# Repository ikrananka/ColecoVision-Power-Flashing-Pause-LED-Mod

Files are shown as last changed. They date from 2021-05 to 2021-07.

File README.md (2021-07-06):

# ColecoVision Power/Flashing Pause LED Mod

## Introduction

This mod for the ColecoVision games console has two functions.  The first is to provide a continuously lit red power LED.  This LED will illuminate whenever the ColecoVision is turned on and not paused.  The second function is to provide a hardwired, physical switch, to pause operation of the ColecoVision allowing you to pause a game at any point and resume play at your leisure.  A unique feature of this mod is that when paused the power/pause LED flashes to indicate that the system is paused.  The rate of flashing is user adjustable from 0.6 to 3.3Hz.  When pause is turned off the flashing LED reverts to being continuously lit (until the system is either paused again or is turned off).
The pause function is achieved by pulling the WAIT line of the ColecoVision’s Z80 CPU low.  This in effect pauses all Z80 processing and therefore pauses the game you’re playing.  However, the audio is not paused and will continue to emit the last note/tone which can be very annoying.  Therefore, this mod not only pauses the Z80 processor but also disconnects the audio output whenever pause is engaged.

The Finished Product


## FAQ

Q.	Will this work with Super Game Module (SGM1) games?

A.	Yes (if you wire the audio as recommended later in this document).  All SGM enhanced games still use the Z80 processor and so they will pause when the Z80 is paused just like any other ColecoVision game.  However, SGM enhanced audio is fed to the ColecoVision via the expansion port (EXAUD), bypassing the ColecoVision’s onboard sound from the SN76489A.  Therefore, it is important that when paused, audio is disconnected from a location after the point where audio from the SN76489A and EXAUD combine.  This is easy to do and instructions for this are provided later in this document.

Q.	Will this work with the upcoming Super Game Module 2 (SGM2)?

A.	Yes and No.  According to the latest information from Opcode Games, the SGM2 will be backwards compatible with SGM1 games and the pause mod will function in the same way as described in the answer above.  However, SGM2 specific games will use the new Z80 and/or 16-bit CPUs that are contained in the SGM2 unit and these cannot be paused using this mod.  However, Opcode Games has stated that “pause will be implemented in software for these games because of the dual CPU design” and so a hardware pause solution is not needed.  You never know, perhaps Opcode Games will make the SGM2s power LED flash when a game is paused!!!

Q.	Does this work with the Expansion Module #1?

A.	No.  The expansion module #1 uses its own processor and audio chip and like the SGM2 cannot be paused by this mod.  Be aware that moving the pause switch to the pause position while playing an expansion module #1 game may disconnect the audio so leave the switch in the normal position when playing these games.

Q.	Is the mod reversable?

A.	The mod is mostly reversable other than the fact that you must drill two large holes in the ColecoVision’s top housing.  These holes are obviously not reversable.

Q. Can the top and bottom halves of the ColecoVision console shell be separated during system maintenance/troubleshooting?

A. Yes.  A pair of 6-pin Molex connectors ae included in the design that when disconnected from each other allow the top and bottom halves of the ColecoVision console shell to be completely separated from each other.

Q.	Can the switch and circuit board be removed for maintenance/troubleshooting?

A.	Yes.  Assuming you don’t use any glue during the installation, which isn’t necessary, then the switch and circuit board can be easily removed.

## The Kit
 
The installation kit contains the following items:
1.	ColecoVision Power/Pause LED Mod PCB.
2.	Motherboard wiring harness.
3.	Pause switch wiring harness (includes pause switch).
4.	Circuit board custom spacer.
5.	Pause switch nut (used to hold switch and circuit board in place).
6.	LED holder.

## Bill of Materials

Please download and refer to the [Bill of Materials](https://github.com/ikrananka/ColecoVision-Power-Flashing-Pause-LED-Mod/blob/main/Bill%20of%20Materials%20v1.0.pdf) contained in this repository.

## Printed Circuit Board

Included in this repository are the PCB schematic and board files created using Eagle v9.1.0.  I have also included Gerber files that are suitable for ordering PCBs from [JLCPCB](https://jlcpcb.com).  If you plan on ordering boards from other PCB manufacturers then you may need to create new gerber files that adhere to that manufacturer's requirements.

### LED Installation

Note that the LED should be soldered onto the underside of the PCB, i.e. the opposite side to all of the other components.  Critically, the LED **MUST** be slightly raised by 0.75mm (30 thou) above the PCB surface as shown below.  I use small pieces of plastic card (0.75mm thick) to do this, held in place with sticky tack, and then solder the LED in place.  Don't forget to remove the pieces of plastic after soldering the LED.

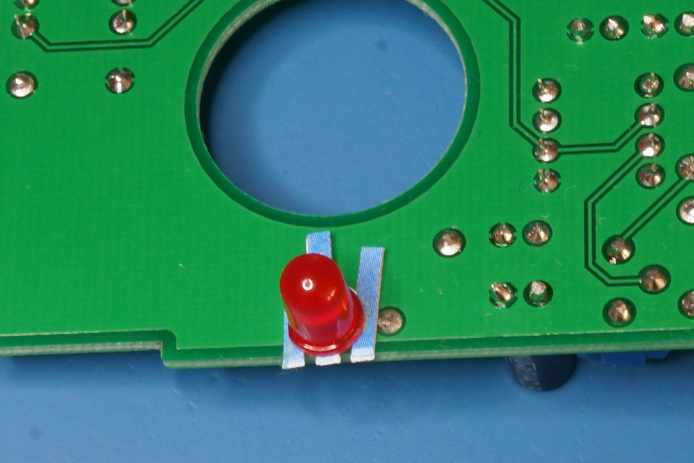
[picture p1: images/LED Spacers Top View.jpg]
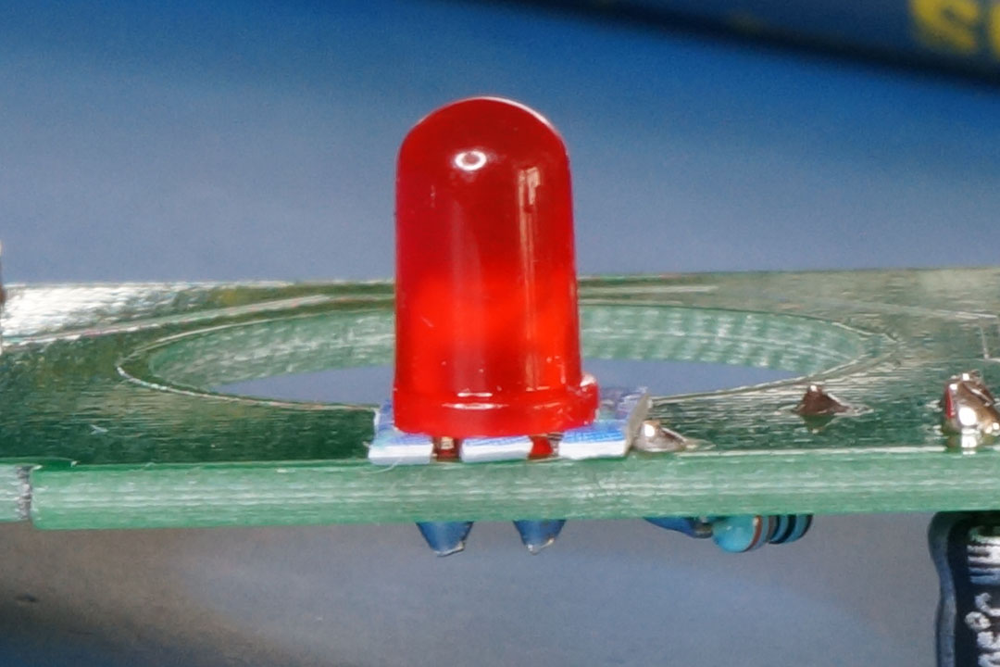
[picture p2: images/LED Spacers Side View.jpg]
 

## Construction of the Wiring Harnesses
### Tools Needed

- Soldering iron and solder
- Wire cutter
- Wire stripper
- Crimping tool (I use a [Waldom W-HT-1921 crimping tool](https://www.digikey.com/en/products/detail/gc-electronics/W-HT-1921/26396)).

### Wire

Note that my preference is to use multistrand (7/32) 24AWG wire for this kit.  Nevertheless, 22AWG multistrand wire would also likely work fine.

### Wire Lengths and Connections

Refer to the following wiring diagram and photographs for details.  Use the appropriate crimps (from the Bill of Materials) for wires that are part of the Molex connectors.  I recommend soldering the wires to the four connections on the back of the rocker switch.

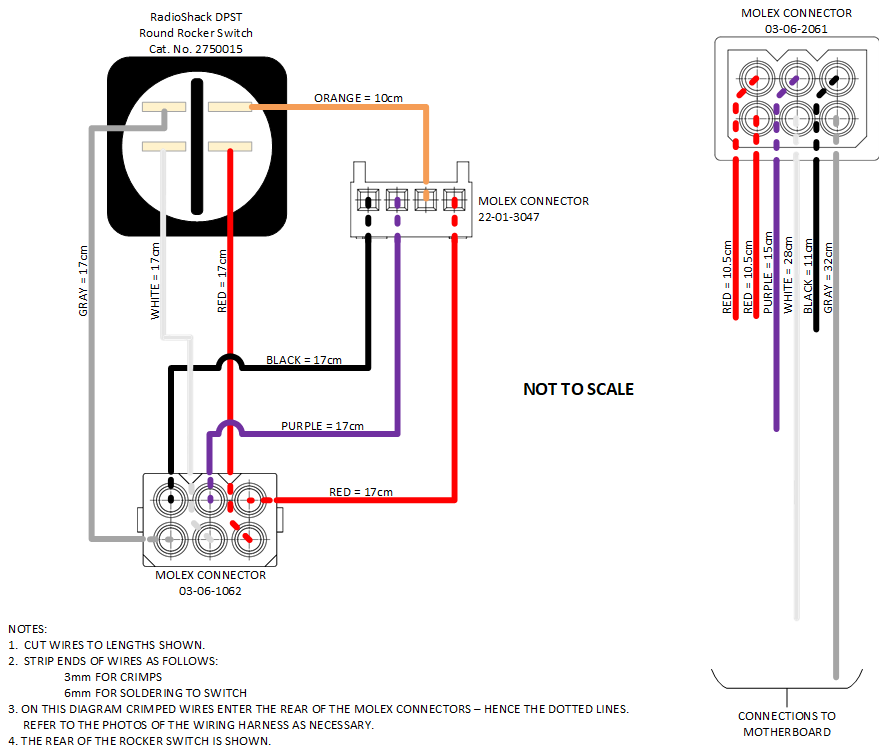
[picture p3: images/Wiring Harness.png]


## The Custom Spacer

The custom spacer provides support under the PCB when tightening the nut that holds the rocker switch and PCB in place.  It is simply a 3D printed circular spacer/washer with the following dimensions:

- ID = 20.5mm
- OD = 26.5mm
- Thickness = 3mm

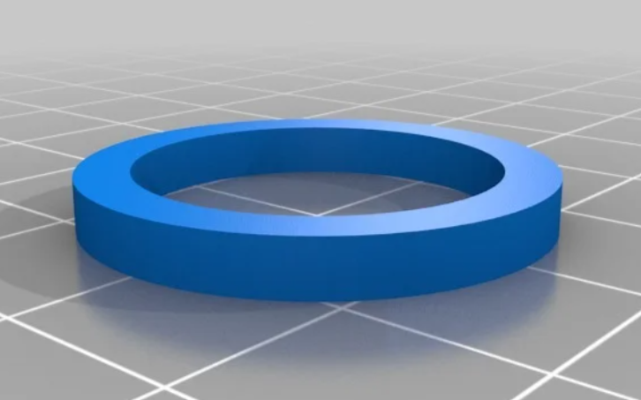
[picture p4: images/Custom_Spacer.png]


You can either download the design from [thingiverse.com](https://www.thingiverse.com/thing:3446247) or from the ["Custom_Spacer.zip"](Custom_Spacer.zip) file included in this repository.

## The Pause Switch Nut

The pause switch nut is included with the purchase of the Radio Shack DPDT switch from the bill of materials.  However, the nut needs to be modified slightly by lightly sanding down the ridges that will press against the PCB when installed.  To do this I typically use 300 grit sandpaper face up on a flat surface and hold the nut with the ridges flat against the sandpaper.  I then slide the nut over the sandpaper in a circular motion while pressing down.  The photo below shows the nut before and after and should give you a good idea of how much of the ridges you need to sand down.  Note that if you don't sand down these ridges then you will find that you won't be able to screw the nut onto the switch when it is installed in the ColecoVision with the spacer and PCB installed.  Sanding down the ridges allows the nut to get close enough to the thread on the switch so that it can be tightened up.

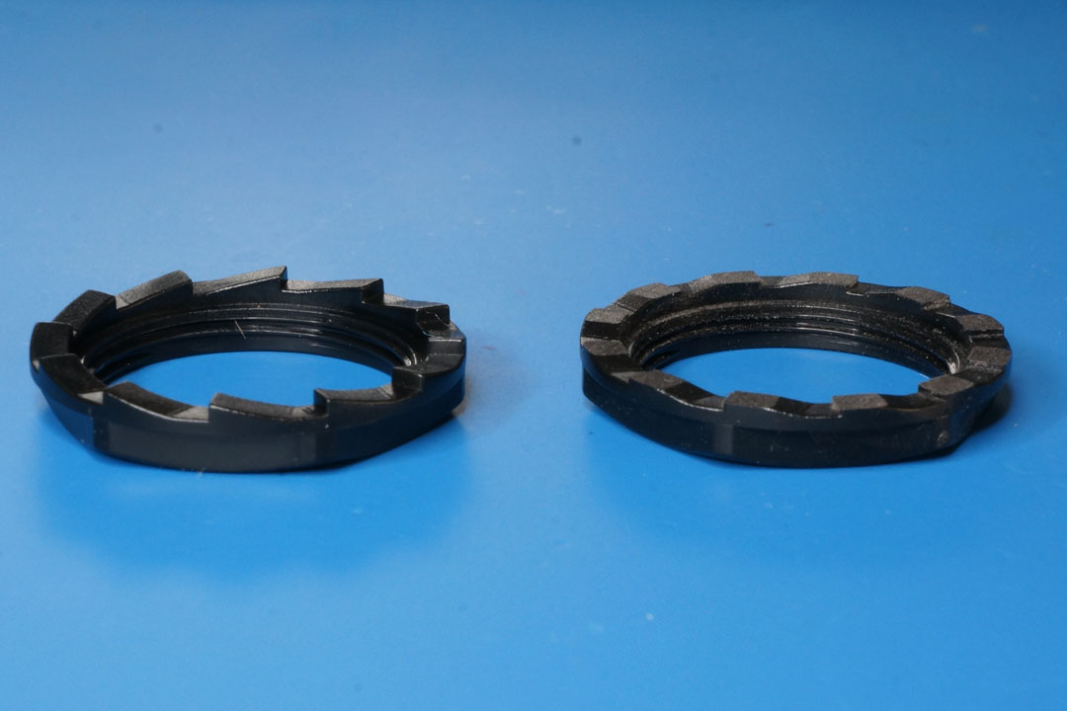
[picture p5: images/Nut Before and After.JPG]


## Installation Instructions

Refer to the [installation instructions pdf](https://github.com/ikrananka/ColecoVision-Power-Flashing-Pause-LED-Mod/blob/main/Installation%20Instructions%20v1.1.pdf) included with this repository.

## Pause Flashing Frequency

The installation instructions include details of how to adjust the flashing frequency.  I have also provided a video to illustrate what different flashing frequncies look like.  You can view the video [here](https://youtu.be/l38Kgi8KPcs).

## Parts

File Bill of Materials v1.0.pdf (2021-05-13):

Name | Description | Quantity | Manufacturer | Manufacturer Part No. | Digi-Key Part No. | Link
PCB | Printed Circuit Board | 1
SWI | DPST 125-Volt Round Rocker Switch | 1 | RadioShack | 2750015 | | https://www.radioshack.com/collections/switches/products/dpst-125v-round-rocker-switch?variant=20332090949
SPC | Custom Spacer/Washer (ID=20.5mm : OD=26.5mm : Thick=3mm) | 1 | | | | https://www.thingiverse.com/thing:3446247
C1 | Ceramic Capacitor - 0.1UF 50V X7R RADIAL | 1 | KEMET Electronics | C320C104K5R5TA7317 | 399-14036-1-ND | https://www.digikey.ca/en/products/detail/kemet/C320C104K5R5TA7317/6562568
C2,C3 | Aluminium Electrolytic Capacitor - 10UF 20% 50V RADIAL | 2 | Panasonic | ECA-1HHG100I | P19445CT-ND | https://www.digikey.ca/en/products/detail/panasonic-electronic-components/ECA-1HHG100I/6221407
C4 | Ceramic Capacitor - 10000PF 100V X7R RADIAL | 1 | KEMET Electronics | C320C103K1R5TA | 399-4260-ND | https://www.digikey.ca/en/products/detail/kemet/C320C103K1R5TA/818036
R1 | Metal Film (Mini) Resistor - 510K OHM 1/4W 1% AXIAL | 1 | Stackpole Electronics | RNMF14FTC510K | S510KCACT-ND | https://www.digikey.ca/en/products/detail/stackpole-electronics-inc/RNMF14FTC510K/2617511
R2 | Metal Film (Mini) Resistor - 150 OHM 1/4W 1% AXIAL | 1 | Stackpole Electronics | RNMF14FTC150R | S150CACT-ND | https://www.digikey.ca/en/products/detail/stackpole-electronics-inc/RNMF14FTC150R/2617812
R3 | Single Turn Trimmer - 100K OHM 0.5W PC PIN TOP | 1 | Nidec Copal Electronics | CT6EP104 | CT6EP104-ND | https://www.digikey.ca/en/products/detail/nidec-copal-electronics/CT6EP104/738305
R4 | Metal Film (Mini) Resistor - 22K OHM 1/4W 1% AXIAL | 1 | Stackpole Electronics | RNMF14FTC22K0 | S22KCACT-ND | https://www.digikey.ca/en/products/detail/stackpole-electronics-inc/RNMF14FTC22K0/2617471
R5 | Metal Film (Mini) Resistor - 330 OHM 1/4W 1% AXIAL | 1 | Stackpole Electronics | RNMF14FTC330R | S330CACT-ND | https://www.digikey.ca/en/products/detail/stackpole-electronics-inc/RNMF14FTC330R/2617488
U1 | Integrated Circuit Analog Switch SPDT - 8-DIP | 1 | Maxim Integrated | MAX4544CPA+ | MAX4544CPA+-ND | https://www.digikey.ca/en/products/detail/maxim-integrated/MAX4544CPA-/1240205
U2 | Integrated Circuit Timer 2.1MHz - 8-DIP | 1 | Texas Instruments | TLC555CP | 296-1857-5-ND | https://www.digikey.ca/en/products/detail/texas-instruments/TLC555CP/277502
LED | Red LED - DIFFUSED 5MM ROUND T/H | 1 | Würth Elektronik | 151051RS11000 | 732-5016-ND | https://www.digikey.ca/en/products/detail/w-rth-elektronik/151051RS11000/4490012
LED_H | LED Holder - PANEL 5MM BLACK NYLON | 1 | Lumex Opto/Components | SSH-LX5091 | 67-1332-ND | https://www.digikey.ca/en/products/detail/lumex-opto-components-inc/SSH-LX5091/144810
X1A | Connection Header Right-Angle - 4POS 2.54MM | 1 | Molex | 22-05-3041 | WM4302-ND | https://www.digikey.ca/en/products/detail/molex/0022053041/26693
X1B | Connection Housing - 4POS .100 W/RAMP/RIB | 1 | Molex | 22-01-3047 | WM2002-ND | https://www.digikey.ca/en/products/detail/molex/0022013047/26435
X1C | Connection Crimp - 22-30AWG TIN | 4 | Molex | 08-50-0114 | WM1114-ND | https://www.digikey.ca/en/products/detail/molex/0008500114/26475
X2A | Connection Receptacle - 6POS .062 | 1 | Molex | 03-06-1062 | 23-0003061062-ND | https://www.digikey.ca/en/products/detail/molex/0003061062/61261
X2B | Connection Plug - 6POS .062 | 1 | Molex | 03-06-2061 | WM1225-ND | https://www.digikey.ca/en/products/detail/molex/0003062061/61220
X2C | Connection Socket Crimp - 18-24AWG TIN | 6 | Molex | 02-06-1103 | WM1001-ND | https://www.digikey.ca/en/products/detail/molex/0002061103/26255
X2D | Connection Pin Crimp - 18-24AWG TIN | 6 | Molex | 02-06-2103 | WM1000-ND | https://www.digikey.ca/en/products/detail/molex/0002062103/26253
Wire | Hook-up Wire - 22 to 24AWG STRANDED
| - White | 46cm
| - Gray | 49cm
| - Black | 28cm
| - Red | 55cm
| - Purple | 32cm
| - Orange | 10cm

# ColecoVision Pause Mod Kit with Power/Flashing Pause LED Bill of Materials

v1.0 (13/May/2021) by Ikrananka

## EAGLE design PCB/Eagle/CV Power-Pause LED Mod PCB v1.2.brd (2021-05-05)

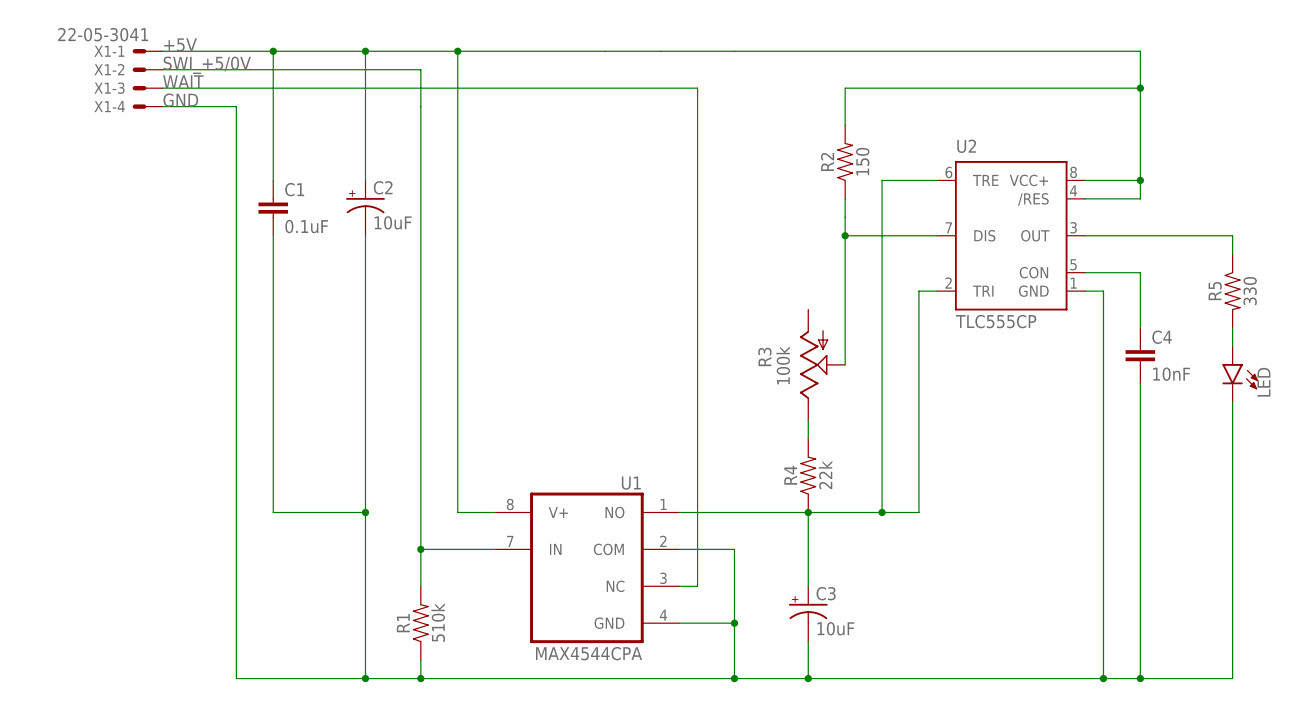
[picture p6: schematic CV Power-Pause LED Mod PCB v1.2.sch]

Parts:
C1: 0.1uF; CAP-PTH-SMALL2
C2, C3: 10uF; E2,5-6
C4: 10nF; CAP-PTH-SMALL2
LED: LED5MM; LED_5MM
R1: 510k; AXIAL-0.3
R2: 150; AXIAL-0.3
R3: 100k; CT6
R4: 22k; AXIAL-0.3
R5: 330; AXIAL-0.3
U1: MAX4544CPA; DIP08
U2: TLC555CP; DIP08
X1: 22-05-3041

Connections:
+5V: C1.1, C2.+, R2.P$2 (2), U1.8 (V+), U2.4 (/RES), U2.8 (VCC+), X1.1
GND: C1.2, C2.-, C3.-, C4.2, LED.K (C), R1.P$1 (1), U1.2 (COM), U1.4 (GND), U2.1 (GND), X1.4
unnamed: LED.A, R5.P$2 (2)
unnamed: C4.1, U2.5 (CON)
unnamed: R2.P$1 (1), R3.S, U2.7 (DIS)
unnamed: R5.P$1 (1), U2.3 (OUT)
unnamed: R3.E, R4.P$2 (2)
unnamed: C3.+, R4.P$1 (1), U1.1 (NO), U2.2 (TRI), U2.6 (TRE)
SWI_+5/0V: R1.P$2 (2), U1.7 (IN), X1.2
WAIT: U1.3 (NC), X1.3

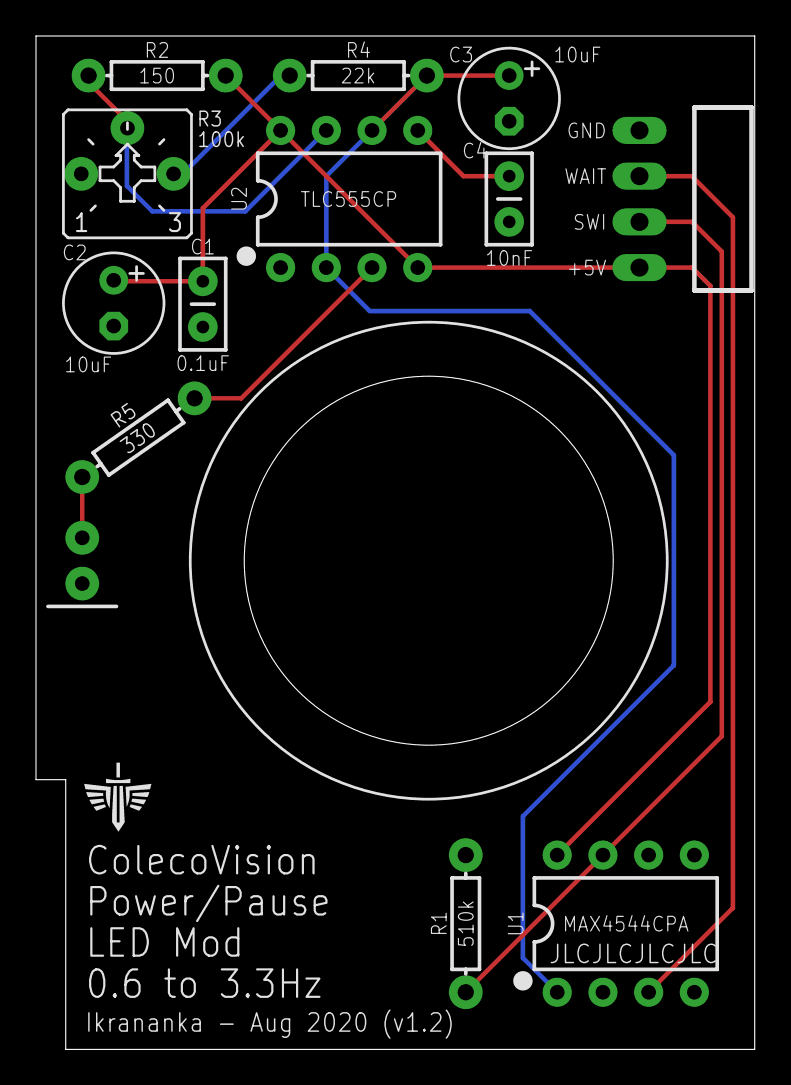
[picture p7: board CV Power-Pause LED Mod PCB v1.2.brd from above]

Board: 2 copper layers, 39.9 x 56.3 mm, 13 parts (1 on the bottom side), 10 nets.

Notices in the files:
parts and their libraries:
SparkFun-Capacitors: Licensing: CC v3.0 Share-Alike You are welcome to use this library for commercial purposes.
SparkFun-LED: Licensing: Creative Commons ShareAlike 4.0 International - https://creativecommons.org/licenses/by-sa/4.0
